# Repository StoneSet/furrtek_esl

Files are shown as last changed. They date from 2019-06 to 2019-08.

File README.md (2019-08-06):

# ESL EMITTER HACK - V1 of 2014

### The Eagle project of the esl project + apk and hex files

**(c) Found the entire project here (not the v1 but u can found it on the web archive): http://furrtek.free.fr/?a=esl**

### TO DO

- Web version of the app (Capability to change page)
- Decompile the app ✅ (Now we will spend many hours to understand the code...)

## Included :

- All needed files to modify the project
- BOM (in /pcb/)
- Prog files & source (not commented) for the APK (in /android/apk/)

## To use it :

1. Buy the pcb then solder every composants.
2. Flash the Attiny85 with phxtx1.hex with these fuses :

- Low: *0xEF*, High: *0xDD*, Extended: *0xFF*

4. Install [pricehax15.apk](https://github.com/StoneSet/furrtek_esl/blob/master/apk/pricehax15.apk  "pricehax15.apk") on your phone (only Android at this time)
5. Plug the jack cable in your phone, launch the app and vouala !

## Some img's :

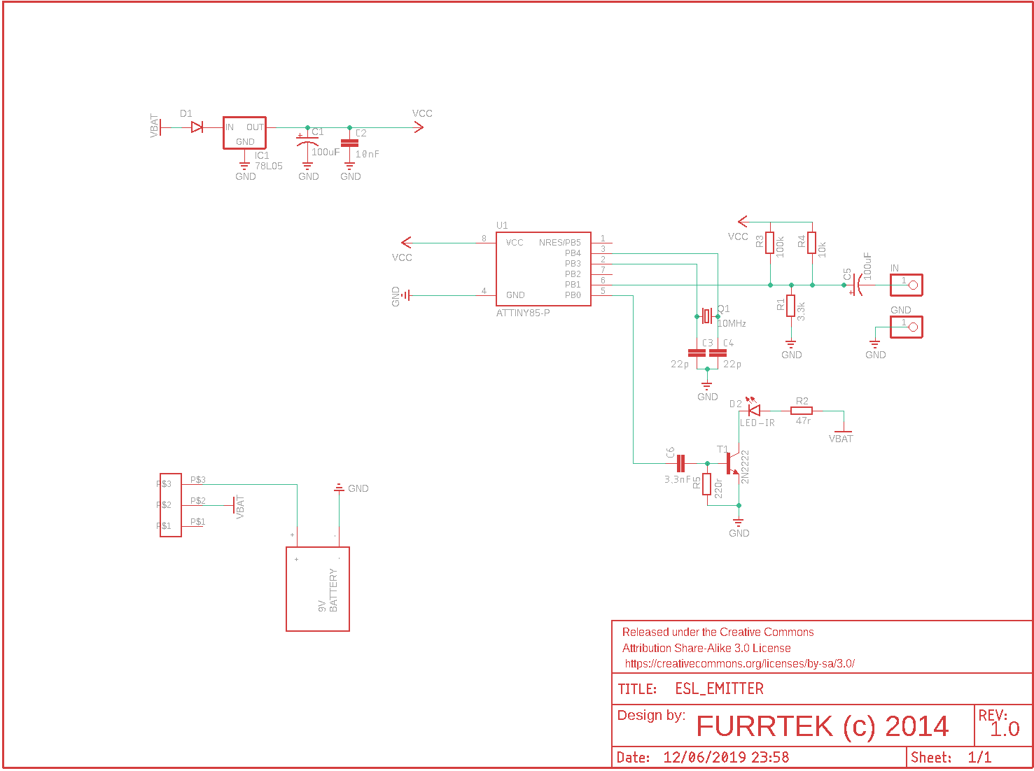
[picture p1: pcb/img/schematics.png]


------


### To dot it, you will need :



| Components | list |
|--|--|
| x1 Attiny85 | x1 78L05 regulator |
| x2 100µF capacitor | x1 10nF ceramic capacitor |
| x2 22pF ceramic capacitor | x1 3.3nF ceramic capacitor |
| x1 10k resistor | x1 100k resistor |
| x1 3.3k resistor | x1 10MHz quartz |
| x1 220ohm resistor | x1 47ohm resistor |
| x1 SFH485P IR LED - 880NM | x1 9v battery clip |
| x1 2N2222 transistor | x1 SPDT Switch |
| x1 A randomly chosen diode |

This version work finely !

#

(c) @furrtek & @StoneSet & @lefuturiste - http://furrtek.free.fr/?a=esl - http://stoneset.github.io/ (2019)

*Prog infos etc here* : [https://github.com/Jonas1312/Pricehax](https://github.com/Jonas1312/Pricehax)

plz do not steal, i'm not the owner of this project, i'm only the owner of this pcb. Have fun !

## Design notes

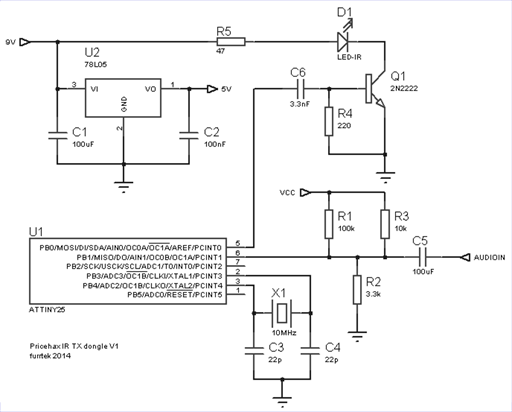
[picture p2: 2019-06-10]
pcb/img/schematics_furrtek.png

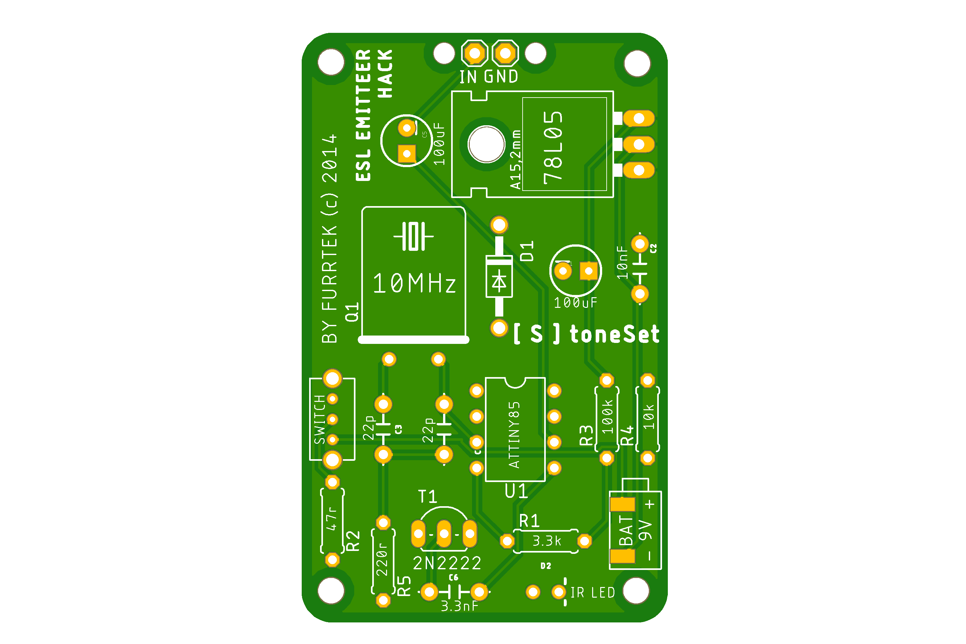
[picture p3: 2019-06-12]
pcb/img/board_top.png

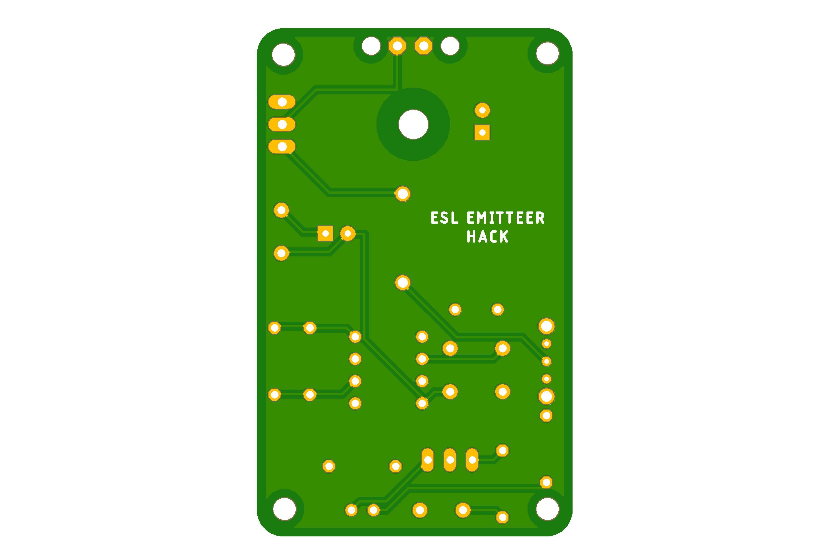
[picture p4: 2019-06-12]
pcb/img/board_bot.png

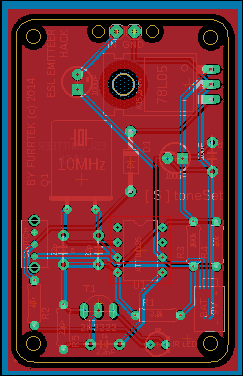
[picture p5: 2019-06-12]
pcb/img/board.png

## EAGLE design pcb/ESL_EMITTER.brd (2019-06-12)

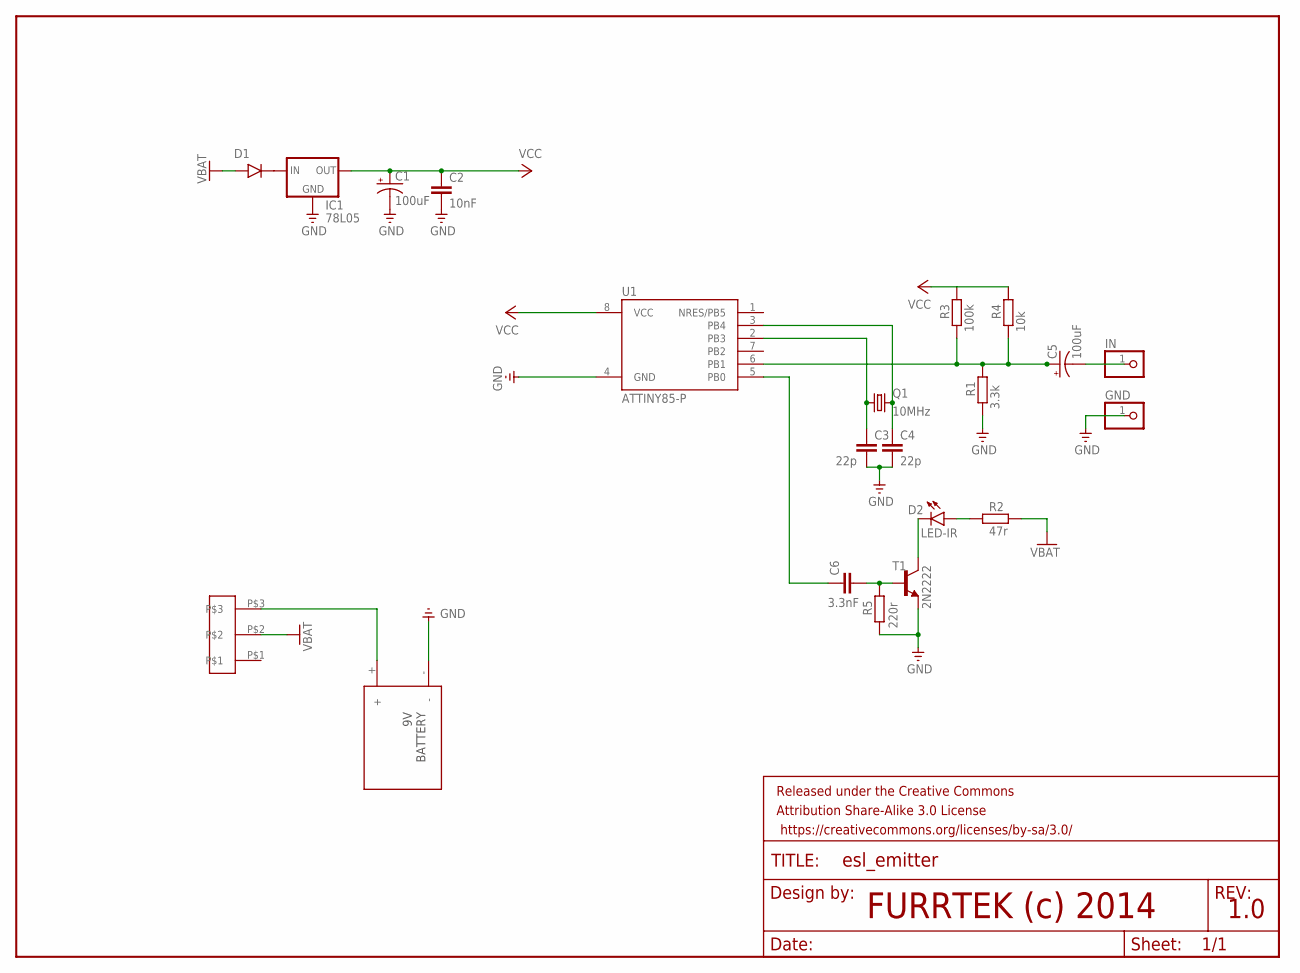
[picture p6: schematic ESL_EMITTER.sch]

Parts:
C1, C5: 100uF; CPOL-RADIAL-10UF-25V
C2: 10nF; CAP-PTH-10MM
C3, C4: 22p; CAP-PTH-10MM
C6: 3.3nF; CAP-PTH-10MM
D1: 1N4001; DO41-10
D2: LED-IR; LED_3MM-NS
FRAME1: FRAME-LETTER; CREATIVE_COMMONS
GND: PINHD-1X1; 1X01
IC1: 78L05; 78XXL
IN: PINHD-1X1; 1X01
Q1: 10MHz; HC49U-H
R1: 3.3k; 0207/7
R2: 47r; 0207/7
R3: 100k; 0207/7
R4: 10k; 0207/7
R5: 220r; 0207/7
T1: 2N2222; TO92-EBC-OVAL
U1: ATTINY85-P; PDIP08_300MIL
U$2: PACKAGESWITCH; SLIDESWITCH
U$3: BAT

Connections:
GND: C1.2 (-), C2.2, C3.2, C4.2, GND.1, IC1.GND, R1.1, R5.1, T1.E, U1.4 (GND), U$3.-
unnamed: D1.C (CATHODE), IC1.IN
unnamed: C4.1, Q1.2, U1.3 (PB4)
unnamed: C3.1, Q1.1, U1.2 (PB3)
unnamed: C5.1 (+), R1.2, R3.1, R4.1, U1.6 (PB1)
unnamed: C6.2, R5.2, T1.B
unnamed: C6.1, U1.5 (PB0)
unnamed: D2.K (C), T1.C
unnamed: C5.2 (-), IN.1
unnamed: U$2.P$3, U$3.+
unnamed: D2.A, R2.1
VBAT: D1.A (ANODE), R2.2, U$2.P$2
VCC: C1.1 (+), C2.1, IC1.OUT, R3.2, R4.2, U1.8 (VCC)

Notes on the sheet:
FURRTEK (c) 2014
1.0

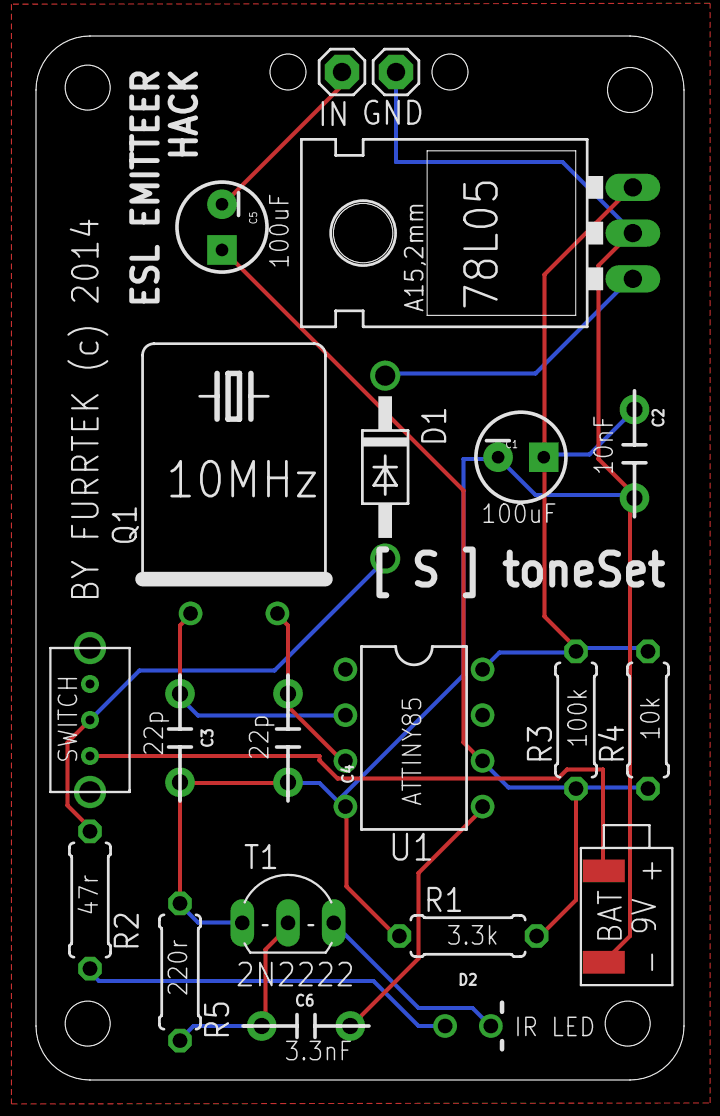
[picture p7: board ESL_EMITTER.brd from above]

Board: 2 copper layers, 36.0 x 58.0 mm, 22 parts (0 on the bottom side), 13 nets.

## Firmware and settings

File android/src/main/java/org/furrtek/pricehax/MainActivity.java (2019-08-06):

package org.furrtek.pricehax;

import android.app.Activity;
import android.bluetooth.BluetoothAdapter;
import android.bluetooth.BluetoothDevice;
import android.bluetooth.BluetoothSocket;
import android.content.Intent;
import android.content.SharedPreferences;
import android.content.SharedPreferences.Editor;
import android.graphics.Bitmap;
import android.graphics.BitmapFactory;
import android.graphics.Color;
import android.graphics.drawable.BitmapDrawable;
import android.hardware.Camera;
import android.hardware.Camera.AutoFocusCallback;
import android.hardware.Camera.Parameters;
import android.hardware.Camera.PreviewCallback;
import android.hardware.Camera.Size;
import android.media.AudioTrack;
import android.os.Bundle;
import android.os.Handler;
import android.os.SystemClock;
import android.support.v4.media.TransportMediator;
import android.support.v4.view.MotionEventCompat;
import android.util.Log;
import android.view.LayoutInflater;
import android.view.View;
import android.view.View.OnClickListener;
import android.view.ViewGroup;
import android.widget.AdapterView;
import android.widget.AdapterView.OnItemSelectedListener;
import android.widget.ArrayAdapter;
import android.widget.Button;
import android.widget.CheckBox;
import android.widget.EditText;
import android.widget.FrameLayout;
import android.widget.ImageView;
import android.widget.ProgressBar;
import android.widget.RadioButton;
import android.widget.SeekBar;
import android.widget.SeekBar.OnSeekBarChangeListener;
import android.widget.Spinner;
import android.widget.SpinnerAdapter;
import android.widget.TabHost;
import android.widget.TabHost.TabSpec;
import android.widget.TextView;
import android.widget.ToggleButton;
import java.io.IOException;
import java.io.InputStream;
import java.io.OutputStream;
import java.util.ArrayList;
import java.util.Iterator;
import java.util.List;
import java.util.Timer;
import java.util.TimerTask;
import java.util.UUID;
import net.sourceforge.zbar.Config;
import net.sourceforge.zbar.Image;
import net.sourceforge.zbar.ImageScanner;
import net.sourceforge.zbar.Symbol;

public class MainActivity extends Activity {
    private static final UUID MY_UUID = UUID.fromString("00001101-0000-1000-8000-00805F9B34FB");
    private static final int SELECT_PHOTO = 100;
    static AudioTrack audioTrack;
    static BluetoothAdapter btAdapter = null;
    static BluetoothSocket btSocket = null;
    static boolean btok = false;
    public static InputStream inStream = null;
    public static OutputStream outStream = null;
    static int transmitVolume;
    Integer PLType;
    final int REQUEST_ENABLE_BT = 1;
    Activity at = this;
    AutoFocusCallback autoFocusCB = new AutoFocusCallback() {
        public void onAutoFocus(boolean z, Camera camera) {
            MainActivity.this.autoFocusHandler.postDelayed(MainActivity.this.doAutoFocus, 1000);
        }
    };
    private Handler autoFocusHandler;
    private boolean barcodeScanned = false;
    private Runnable doAutoFocus = new Runnable() {
        public void run() {
            if (MainActivity.this.previewing && MainActivity.this.tabHost.getCurrentTab() == 1 && MainActivity.this.mCamera != null) {
                MainActivity.this.mCamera.autoFocus(MainActivity.this.autoFocusCB);
            }
        }
    };
    int donglever;
    Handler handler = new Handler();
    int hi;
    InputStream imageStream = null;
    ImageView imgbmp;
    TextView label_plhex;
    private Camera mCamera;
    private CameraPreview mPreview;
    ProgressBar pgb;
    int plBitDef;
    long plID;
    FrameLayout preview;
    PreviewCallback previewCb = new PreviewCallback() {
        public void onPreviewFrame(byte[] bArr, Camera camera) {
            Size previewSize = camera.getParameters().getPreviewSize();
            Image image = new Image(previewSize.width, previewSize.height, "Y800");
            image.setData(bArr);
            if (MainActivity.this.scanner.scanImage(image) != 0) {
                MainActivity.this.previewing = false;
                MainActivity.this.mCamera.setPreviewCallback(null);
                MainActivity.this.mCamera.stopPreview();
                Iterator it = MainActivity.this.scanner.getResults().iterator();
                while (it.hasNext()) {
                    String data = ((Symbol) it.next()).getData();
                    MainActivity.this.plID = (long) ((Integer.parseInt(data.substring(2, 7)) << 16) + Integer.parseInt(data.substring(7, 12)));
                    String toHexString = Long.toHexString(MainActivity.this.plID);
                    MainActivity.this.PLType = Integer.valueOf(Integer.parseInt(data.substring(12, 16)));
                    MainActivity.this.scaneibarcode.setText("Barcode: " + data);
                    MainActivity.this.scaneiserial.setText("ID: " + toHexString.toUpperCase());
                    switch (MainActivity.this.PLType.intValue()) {
                        case 1206:
                            MainActivity.this.scaneitype.setText("Type: " + MainActivity.this.PLType + " (E2 HCS)");
                            break;
                        case 1207:
                            MainActivity.this.scaneitype.setText("Type: " + MainActivity.this.PLType + " (E2 HCN)");
                            MainActivity.this.plBitDef = 4;
                            break;
                        case 1217:
                        case 1265:
                            MainActivity.this.scaneitype.setText("Type: " + MainActivity.this.PLType + " (E5 SMALL)");
                            MainActivity.this.plBitDef = 2;
                            break;
                        case 1219:
                            MainActivity.this.scaneitype.setText("Type: " + MainActivity.this.PLType + " (E5 MEDIUM)");
                            MainActivity.this.plBitDef = 1;
                            break;
                        case 1240:
                            MainActivity.this.scaneitype.setText("Type: " + MainActivity.this.PLType + " (E4 HCS)");
                            MainActivity.this.plBitDef = 3;
                            break;
                        case 1241:
                            MainActivity.this.scaneitype.setText("Type: " + MainActivity.this.PLType + " (E4 HCN)");
                            break;
                        case 1242:
                            MainActivity.this.scaneitype.setText("Type: " + MainActivity.this.PLType + " (E4 HCN FZ)");
                            MainActivity.this.plBitDef = 0;
                            break;
                        case 1300:
                            MainActivity.this.scaneitype.setText("Type: " + MainActivity.this.PLType + " (DotMatrix 172x72)");
                            MainActivity.this.wi = 172;
                            MainActivity.this.hi = 72;
                            break;
                        case 1318:
                            MainActivity.this.scaneitype.setText("Type: " + MainActivity.this.PLType + " (ST 208x112)");
                            MainActivity.this.wi = 208;
                            MainActivity.this.hi = 112;
                            break;
                        default:
                            MainActivity.this.scaneitype.setText("Type: " + MainActivity.this.PLType + " (incompatible)");
                            break;
                    }
                    MainActivity.this.barcodeScanned = true;
                }
            }
        }
    };
    private boolean previewing = true;
    byte[] rawbitstream = new byte[23296];
    private boolean repeatMode = false;
    private boolean repeatModeDM = false;
    Bitmap scaledimage;
    Button scanButton;
    TextView scaneibarcode;
    TextView scaneiserial;
    TextView scaneitype;
    ImageScanner scanner;
    SharedPreferences settings;
    Spinner spinner;
    TabHost tabHost;
    int tabPos;
    Timer timer;
    Timer timerdm;
    TextView txtworkh;
    int wi;
    int x;
    int y;
    int ymax;

    static {
        System.loadLibrary("iconv");
    }

    private static void checkBTState() {
        if (btAdapter == null) {
            Log.d("BT", "NO BT ADAPTER");
        } else if (btAdapter.isEnabled()) {
            Log.d("BT", "BT ENABLED");
            BluetoothDevice bluetoothDevice = null;
            for (BluetoothDevice bluetoothDevice2 : btAdapter.getBondedDevices()) {
                BluetoothDevice bluetoothDevice22;
                Log.d("BT", "LIST: " + bluetoothDevice22.getName());
                if (bluetoothDevice22.getName().equals("PRICEHAX TX V3")) {
                    bluetoothDevice22 = btAdapter.getRemoteDevice(bluetoothDevice22.getAddress());
                    Log.d("BT", "FOUND BT PRICEHAX TX V3 :)");
                    bluetoothDevice = bluetoothDevice22;
                }
            }
            if (bluetoothDevice != null) {
                try {
                    btSocket = bluetoothDevice.createRfcommSocketToServiceRecord(MY_UUID);
                } catch (IOException e) {
                    Log.d("BT", "EXCEPTION IN RF COMM SOCKET CREATION");
                }
                btAdapter.cancelDiscovery();
                Log.d("BT", "CONNECTING...");
                try {
                    btSocket.connect();
                    btok = true;
                    Log.d("BT", "CONNECTION OK");
                } catch (IOException e2) {
                    try {
                        btSocket.close();
                    } catch (IOException e3) {
                        Log.d("BT", "EXCEPTION IN CONNECT");
                    }
                }
                try {
                    outStream = btSocket.getOutputStream();
                    inStream = btSocket.getInputStream();
                } catch (IOException e4) {
                    Log.d("BT", "EXCEPTION IN STREAM CREATION");
                }
            }
        }
    }

    public static Camera getCameraInstance() {
        try {
            return Camera.open(0);
        } catch (Exception e) {
            return null;
        }
    }

    private void releaseCamera() {
        if (this.mCamera != null) {
            this.previewing = false;
            this.mCamera.setPreviewCallback(null);
            this.mCamera.release();
            this.mCamera = null;
        }
    }

    public void convertImage(View view) {
        new Thread(new Runnable() {
            public void run() {
                int i;
                int i2;
                int pixel;
                MainActivity.this.txtworkh = (TextView) MainActivity.this.findViewById(R.id.txtwork);
                MainActivity.this.pgb = (ProgressBar) MainActivity.this.findViewById(R.id.pgb1);
                MainActivity.this.imgbmp = (ImageView) MainActivity.this.findViewById(R.id.imgvbmp);
                MainActivity.this.scaledimage = ((BitmapDrawable) MainActivity.this.imgbmp.getDrawable()).getBitmap();
                if (MainActivity.this.PLType.intValue() == 1318) {
                    i = 208;
                    i2 = 112;
                } else {
                    i = 172;
                    i2 = 72;
                }
                MainActivity.this.wi = i;
                MainActivity.this.hi = i2;
                MainActivity.this.scaledimage = Bitmap.createScaledBitmap(MainActivity.this.scaledimage, MainActivity.this.wi, MainActivity.this.hi, true);
                int i3 = 0;
                MainActivity.this.y = 0;
                while (MainActivity.this.y < i2) {
                    MainActivity mainActivity;
                    MainActivity.this.x = 0;
                    while (MainActivity.this.x < i) {
                        pixel = MainActivity.this.scaledimage.getPixel(MainActivity.this.x, MainActivity.this.y);
                        if (((int) (((((double) Color.green(pixel)) * 0.587d) + (0.299d * ((double) Color.red(pixel)))) + (0.114d * ((double) Color.blue(pixel))))) < 128) {
                            MainActivity.this.rawbitstream[i3] = (byte) 0;
                        } else {
                            MainActivity.this.rawbitstream[i3] = (byte) 1;
                        }
                        mainActivity = MainActivity.this;
                        mainActivity.x++;
                        i3++;
                    }
                    MainActivity.this.handler.post(new Runnable() {
                        public void run() {
                            MainActivity.this.pgb.setProgress((MainActivity.this.y * 36) / MainActivity.this.wi);
                        }
                    });
                    MainActivity.this.runOnUiThread(new Runnable() {
                        public void run() {
                            MainActivity.this.txtworkh.setText("Converting to monochrome: line " + MainActivity.this.y);
                        }
                    });
                    try {
                        Thread.sleep(5);
                    } catch (InterruptedException e) {
                        e.printStackTrace();
                    }
                    mainActivity = MainActivity.this;
                    mainActivity.y++;
                }
                int i4 = i3 - 1;
                byte b = MainActivity.this.rawbitstream[0];
                MainActivity.this.y = 0;
                List<Integer> arrayList = new ArrayList();
                MainActivity.this.runOnUiThread(new Runnable() {
                    public void run() {
                        MainActivity.this.txtworkh.setText("RLE compress...");
                    }
                });
                pixel = 1;
                byte b2 = b;
                i = 1;
                byte b3 = b2;
                while (i <= i4) {
                    byte b4 = MainActivity.this.rawbitstream[i];
                    if (b4 == b3) {
                        i2 = pixel + 1;
                        if (i == i4 - 1) {
                            arrayList.add(Integer.valueOf(i2));
                        }
                    } else {
                        arrayList.add(Integer.valueOf(pixel));
                        i2 = 1;
                        if (i == i4 - 1) {
                            arrayList.add(Integer.valueOf(1));
                        }
                    }
                    if ((i & 31) == 0) {
                        MainActivity.this.handler.post(new Runnable() {
                            public void run() {
                                MainActivity.this.pgb.setProgress((MainActivity.this.y / 1238) + 36);
                            }
                        });
                        try {
                            Thread.sleep(1);
                        } catch (InterruptedException e2) {
                            e2.printStackTrace();
                        }
                    }
                    i++;
                    mainActivity = MainActivity.this;
                    mainActivity.y++;
                    pixel = i2;
                    b3 = b4;
                }
                MainActivity.this.runOnUiThread(new Runnable() {
                    public void run() {
                        MainActivity.this.txtworkh.setText("Hexadecimalifying...");
                    }
                });
                StringBuilder stringBuilder = new StringBuilder();
                stringBuilder.append(MainActivity.this.rawbitstream[0]);
                for (Integer intValue : arrayList) {
                    String toBinaryString = Integer.toBinaryString(intValue.intValue());
                    StringBuffer stringBuffer = new StringBuffer(toBinaryString.length());
                    for (i2 = 0; i2 < toBinaryString.length() - 1; i2++) {
                        stringBuffer.append("0");
                    }
                    stringBuilder.append(stringBuffer.toString());
                    stringBuilder.append(toBinaryString);
                }
                i2 = stringBuilder.toString().length() % 320;
                if (i2 > 0) {
                    i2 = 320 - i2;
                }
                for (i = 0; i < i2; i++) {
                    stringBuilder.append("0");
                }
                String stringBuilder2 = stringBuilder.toString();
                List arrayList2 = new ArrayList();
                for (i2 = 0; i2 < stringBuilder2.length(); i2 += 8) {
                    arrayList2.add(Byte.valueOf((byte) Integer.parseInt(stringBuilder2.substring(i2, i2 + 8), 2)));
                }
                int size = arrayList2.size();
                try {
                    Thread.sleep(400);
                } catch (InterruptedException e3) {
                    e3.printStackTrace();
                }
                MainActivity.this.handler.post(new Runnable() {
                    public void run() {
                        MainActivity.this.pgb.setProgress(MainActivity.SELECT_PHOTO);
                    }
                });
                MainActivity.audioTrack = new AudioTrack(3, 48000, 4, 2, 48000, 1);
                byte[] bArr = new byte[]{(byte) -123, (byte) 0, (byte) 0, (byte) 0, (byte) 0, (byte) -105, (byte) 1, (byte) 0, (byte) 0, (byte) 0, (byte) 1, (byte) 1, (byte) 1, (byte) 1, (byte) 1, (byte) 1, (byte) 1, (byte) 1, (byte) 1, (byte) 1, (byte) 1, (byte) 1, (byte) 1, (byte) 1, (byte) 1, (byte) 1, (byte) 1, (byte) 1, (byte) 1, (byte) 1, (byte) 1, (byte) 1};
                bArr[1] = (byte) ((int) (255 & MainActivity.this.plID));
                bArr[2] = (byte) ((int) (MainActivity.this.plID >> 8));
                bArr[3] = (byte) ((int) (MainActivity.this.plID >> 16));
                bArr[4] = (byte) ((int) (MainActivity.this.plID >> 24));
                byte[] GetCRC = CRCCalc.GetCRC(bArr, 30);
                bArr[30] = GetCRC[0];
                bArr[31] = GetCRC[1];
                MainActivity.this.runOnUiThread(new Runnable() {
                    public void run() {
                        MainActivity.this.txtworkh.setText("Waking up ESL...");
                    }
                });
                PP4C.sendPP4C(MainActivity.this.at.getApplicationContext(), bArr, 32, MainActivity.this.donglever, 50, MainActivity.audioTrack);
                if (MainActivity.this.donglever == 2) {
                    SystemClock.sleep(4600);
                } else if (MainActivity.this.donglever == 1) {
                    SystemClock.sleep(1800);
                    PP4C.sendPP4C(MainActivity.this.at.getApplicationContext(), bArr, 32, MainActivity.this.donglever, 35, MainActivity.audioTrack);
                    SystemClock.sleep(1800);
                    PP4C.sendPP4C(MainActivity.this.at.getApplicationContext(), bArr, 32, MainActivity.this.donglever, 35, MainActivity.audioTrack);
                    SystemClock.sleep(1800);
                }
                bArr = new byte[54];
                bArr[0] = (byte) -123;
                bArr[1] = (byte) ((int) (255 & MainActivity.this.plID));
                bArr[2] = (byte) ((int) (MainActivity.this.plID >> 8));
                bArr[3] = (byte) ((int) (MainActivity.this.plID >> 16));
                bArr[4] = (byte) ((int) (MainActivity.this.plID >> 24));
                bArr[5] = (byte) 52;
                bArr[6] = (byte) 0;
                bArr[7] = (byte) 0;
                bArr[8] = (byte) 0;
                bArr[9] = (byte) 5;
                bArr[10] = (byte) (size >> 8);
                bArr[11] = (byte) (size & MotionEventCompat.ACTION_MASK);
                byte[] bArr2;
                if (MainActivity.this.PLType.intValue() == 1318) {
                    bArr2 = new byte[]{(byte) 0, (byte) 2, (byte) 3, (byte) 0, (byte) -48, (byte) 0, (byte) 112, (byte) 0, (byte) 0, (byte) 0, (byte) 0, (byte) 0, (byte) 0, (byte) -120, (byte) 0, (byte) 0, (byte) 0, (byte) 0, (byte) 0, (byte) 0};
                    for (i2 = 0; i2 < 20; i2++) {
                        bArr[i2 + 12] = bArr2[i2];
                    }
                } else {
                    bArr2 = new byte[]{(byte) 0, (byte) 2, (byte) 4, (byte) 0, (byte) -84, (byte) 0, (byte) 72, (byte) 0, (byte) 0, (byte) 0, (byte) 0, (byte) 0, (byte) 0, (byte) -120, (byte) 0, (byte) 0, (byte) 0, (byte) 0, (byte) 0, (byte) 0};
                    for (i2 = 0; i2 < 20; i2++) {
                        bArr[i2 + 12] = bArr2[i2];
                    }
                }
                GetCRC = CRCCalc.GetCRC(bArr, 32);
                bArr[32] = GetCRC[0];
                bArr[33] = GetCRC[1];
                MainActivity.this.runOnUiThread(new Runnable() {
                    public void run() {
                        MainActivity.this.txtworkh.setText("Start frame...");
                    }
                });
                PP4C.sendPP4C(MainActivity.this.at.getApplicationContext(), bArr, 34, MainActivity.this.donglever, 6, MainActivity.audioTrack);
                if (MainActivity.this.donglever == 2) {
                    SystemClock.sleep(1000);
                }
                if (MainActivity.this.donglever == 1) {
                    SystemClock.sleep(1600);
                }
                MainActivity.this.ymax = size / 40;
                MainActivity.this.y = 0;
                while (MainActivity.this.y < size / 40) {
                    bArr[0] = (byte) -123;
                    bArr[1] = (byte) ((int) (255 & MainActivity.this.plID));
                    bArr[2] = (byte) ((int) (MainActivity.this.plID >> 8));
                    bArr[3] = (byte) ((int) (MainActivity.this.plID >> 16));
                    bArr[4] = (byte) ((int) (MainActivity.this.plID >> 24));
                    bArr[5] = (byte) 52;
                    bArr[6] = (byte) 0;
                    bArr[7] = (byte) 0;
                    bArr[8] = (byte) 0;
                    bArr[9] = (byte) 32;
                    bArr[10] = (byte) (MainActivity.this.y >> 16);
                    bArr[11] = (byte) (MainActivity.this.y & MotionEventCompat.ACTION_MASK);
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

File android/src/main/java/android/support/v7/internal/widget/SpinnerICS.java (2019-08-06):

package android.support.v7.internal.widget;

import android.app.AlertDialog;
import android.app.AlertDialog.Builder;
import android.content.Context;
import android.content.DialogInterface;
import android.content.DialogInterface.OnClickListener;
import android.content.res.TypedArray;
import android.database.DataSetObserver;
import android.graphics.Rect;
import android.graphics.drawable.Drawable;
import android.support.v4.widget.ExploreByTouchHelper;
import android.support.v7.appcompat.R;
import android.support.v7.internal.widget.AdapterViewICS.OnItemClickListener;
import android.util.AttributeSet;
import android.view.View;
import android.view.View.MeasureSpec;
import android.view.ViewGroup;
import android.view.ViewGroup.LayoutParams;
import android.widget.ListAdapter;
import android.widget.SpinnerAdapter;

class SpinnerICS extends AbsSpinnerICS implements OnClickListener {
    private static final int MAX_ITEMS_MEASURED = 15;
    static final int MODE_DIALOG = 0;
    static final int MODE_DROPDOWN = 1;
    private static final int MODE_THEME = -1;
    private static final String TAG = "Spinner";
    int mDropDownWidth;
    private int mGravity;
    private SpinnerPopup mPopup;
    private DropDownAdapter mTempAdapter;
    private Rect mTempRect;

    private interface SpinnerPopup {
        void dismiss();

        CharSequence getHintText();

        boolean isShowing();

        void setAdapter(ListAdapter listAdapter);

        void setPromptText(CharSequence charSequence);

        void show();
    }

    private class DialogPopup implements SpinnerPopup, OnClickListener {
        private ListAdapter mListAdapter;
        private AlertDialog mPopup;
        private CharSequence mPrompt;

        private DialogPopup() {
        }

        public void dismiss() {
            this.mPopup.dismiss();
            this.mPopup = null;
        }

        public CharSequence getHintText() {
            return this.mPrompt;
        }

        public boolean isShowing() {
            return this.mPopup != null ? this.mPopup.isShowing() : false;
        }

        public void onClick(DialogInterface dialogInterface, int i) {
            SpinnerICS.this.setSelection(i);
            if (SpinnerICS.this.mOnItemClickListener != null) {
                SpinnerICS.this.performItemClick(null, i, this.mListAdapter.getItemId(i));
            }
            dismiss();
        }

        public void setAdapter(ListAdapter listAdapter) {
            this.mListAdapter = listAdapter;
        }

        public void setPromptText(CharSequence charSequence) {
            this.mPrompt = charSequence;
        }

        public void show() {
            Builder builder = new Builder(SpinnerICS.this.getContext());
            if (this.mPrompt != null) {
                builder.setTitle(this.mPrompt);
            }
            this.mPopup = builder.setSingleChoiceItems(this.mListAdapter, SpinnerICS.this.getSelectedItemPosition(), this).show();
        }
    }

    private static class DropDownAdapter implements ListAdapter, SpinnerAdapter {
        private SpinnerAdapter mAdapter;
        private ListAdapter mListAdapter;

        public DropDownAdapter(SpinnerAdapter spinnerAdapter) {
            this.mAdapter = spinnerAdapter;
            if (spinnerAdapter instanceof ListAdapter) {
                this.mListAdapter = (ListAdapter) spinnerAdapter;
            }
        }

        public boolean areAllItemsEnabled() {
            ListAdapter listAdapter = this.mListAdapter;
            return listAdapter != null ? listAdapter.areAllItemsEnabled() : true;
        }

        public int getCount() {
            return this.mAdapter == null ? 0 : this.mAdapter.getCount();
        }

        public View getDropDownView(int i, View view, ViewGroup viewGroup) {
            return this.mAdapter == null ? null : this.mAdapter.getDropDownView(i, view, viewGroup);
        }

        public Object getItem(int i) {
            return this.mAdapter == null ? null : this.mAdapter.getItem(i);
        }

        public long getItemId(int i) {
            return this.mAdapter == null ? -1 : this.mAdapter.getItemId(i);
        }

        public int getItemViewType(int i) {
            return 0;
        }

        public View getView(int i, View view, ViewGroup viewGroup) {
            return getDropDownView(i, view, viewGroup);
        }

        public int getViewTypeCount() {
            return 1;
        }

        public boolean hasStableIds() {
            return this.mAdapter != null && this.mAdapter.hasStableIds();
        }

        public boolean isEmpty() {
            return getCount() == 0;
        }

        public boolean isEnabled(int i) {
            ListAdapter listAdapter = this.mListAdapter;
            return listAdapter != null ? listAdapter.isEnabled(i) : true;
        }
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

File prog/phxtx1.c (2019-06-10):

// Pricehax IR TX dongle firmware V1 for schematic V1
// furrtek 2014 - furrtek.org
// Apache License 2.0

// Code data buffering can be optimized a lot by doing bit-by-bit storage instead of byte-per-byte !

#define F_CPU 10000000

#include <avr/io.h>
#include <util/delay.h>
#include <inttypes.h>
#include <avr/interrupt.h>

volatile uint16_t codeptr = 0;
volatile uint8_t dcode[480];

#define NOP __asm__ __volatile__ ("nop")

ISR(TIMER1_OVF_vect) {
	uint8_t r,d;
	uint16_t pp;

	if (codeptr) {
		
		// PP4C playback magic !
		
		for (r=0;r<50;r++) {
			for (pp=0;pp<(codeptr-1);pp+=2) {
				TCCR0A = 0b01000010;
				TCCR0B = 0b00000001;
				_delay_us(39);			// 39 +1 -2 0 -2
				NOP;
				NOP;
				NOP;
				NOP;
				NOP;
				NOP;
				NOP;
				NOP;
				TCCR0A = 0b00000010;
				TCCR0B = 0b00000000;
				PORTB = 0;
				d = ((dcode[pp]<<1)+dcode[pp+1]);
				switch(d) {
				case 0:
					_delay_us(60-4);
					NOP;
					NOP;
					NOP;
					NOP;
					NOP;
					NOP;
					NOP;
					NOP;
					break;
				case 1:
					_delay_us(60+60+60+60-3);
					NOP;
					NOP;
					NOP;
					NOP;
					NOP;
					NOP;
					NOP;
					NOP;
					NOP;
					NOP;
					NOP;
					break;
				case 2:
					_delay_us(60+60-3);
					NOP;
					NOP;
					NOP;
					NOP;
					NOP;
					NOP;
					NOP;
					NOP;
					NOP;
					break;
				case 3:
					_delay_us(60+60+60-2);
					break;
				}
			}
			TCCR0A = 0b01000010;
			TCCR0B = 0b00000001;
			_delay_us(39);			// 39 +1 -2 0 -2
			NOP;
			NOP;
			NOP;
			NOP;
			NOP;
			NOP;
			NOP;
			NOP;
			TCCR0A = 0b00000010;
			TCCR0B = 0b00000000;
			PORTB = 0;
			_delay_us(2000);
		}
	}
	codeptr = 0;
	ACSR = 0b01001010;
}

ISR(ANA_COMP_vect) {
	uint8_t tcval;

	tcval = TCNT1;
	TCNT1 = 0;

	if (codeptr) {
		if (tcval > 128)
			dcode[codeptr-1] = 0;
		else
			dcode[codeptr-1] = 1;
	}

	codeptr++;
}

int main(void) {
	WDTCR = (1<<WDCE) | (1<<WDE);
	WDTCR = 0x00;

	PORTB = 0;
	DDRB = 1;

	OCR0A = 3;	// 10/2/8=1.25MHz

	ACSR = 0b01001011;	//10
	DIDR0 = 0b00000010;

	TCCR1 = 0b00000101;
	TIMSK = 0b00000100;

	sei();

	for(;;) {}
}

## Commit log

2019-06-12 feat(labels): add labels & some fix
    [ESL_EMITTER.brd, ESL_EMITTER.sch]
2019-06-12 fix: wrong img (board&schematics)
2019-06-12 fix: capacitor&bom : last release
    [ESL_EMITTER.brd, ESL_EMITTER.sch]
2019-06-12 fix: iam idiot
    [ESL_EMITTER.brd]
2019-07-21 feat(infos): add bom, update imgs etc
2019-08-06 feat(refactor): refactor the repo & the readme
    [ESL_EMITTER.brd, ESL_EMITTER.sch]

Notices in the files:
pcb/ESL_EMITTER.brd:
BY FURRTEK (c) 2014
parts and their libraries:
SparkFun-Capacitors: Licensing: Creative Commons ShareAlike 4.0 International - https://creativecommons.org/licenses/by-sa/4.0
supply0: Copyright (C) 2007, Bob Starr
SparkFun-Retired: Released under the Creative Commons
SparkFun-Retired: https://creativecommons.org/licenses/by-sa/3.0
